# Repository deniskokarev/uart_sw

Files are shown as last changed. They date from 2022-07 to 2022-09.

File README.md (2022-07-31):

# UART Switch

This is a helper debugging device to switch the output of a proprietary box. The box connects via 2x4 Header.
There are 3 operation modes when the corresponding pins are connected:
- 0 Off: neither pins connected
- 1 SOC: (2 <-> 3) (5 <-> 6)
- 2 DBG: (2 <-> 1) (5 <-> 4) 

The device is based on STM32 microcontroller. DipTrace was used for hardware schematics and layout.
CubeMX used for USB CDC application template generaion. CLion for the rest of firmware development.

---------------------
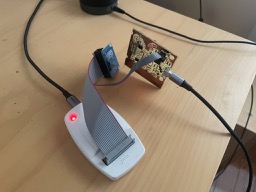
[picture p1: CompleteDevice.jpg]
Complete Device

---------------------

The modes may be switched either with a button or via serial terminal

- Directly from command line
```
echo -n "2" >/dev/cu.usbmodem1D11
```
- By Using `screen`
```
screen /dev/cu.usbmodem1D11
```
Screen Serial Terminal

The device is shows up in the USB list

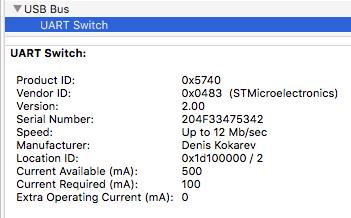
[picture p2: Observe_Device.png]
Observe in the USB device list


## [Hardware](./hardware)

## [Firmware](./firmware)

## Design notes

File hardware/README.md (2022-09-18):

# Schematic and Board Layout

The schematic and board layout was developed using DipTrace.

Schematics PDF Schematic PDF

## TODO

Fix some hardware bugs:
1) Smaller pad for inductor L1

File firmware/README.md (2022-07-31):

# Firmware

The template created with Cube MX. The code is developed using CLion.

You can tweak firmware.ioc in Cube MX and regenerate the code. Then you can continue development in CLion.

Current pins assignment:
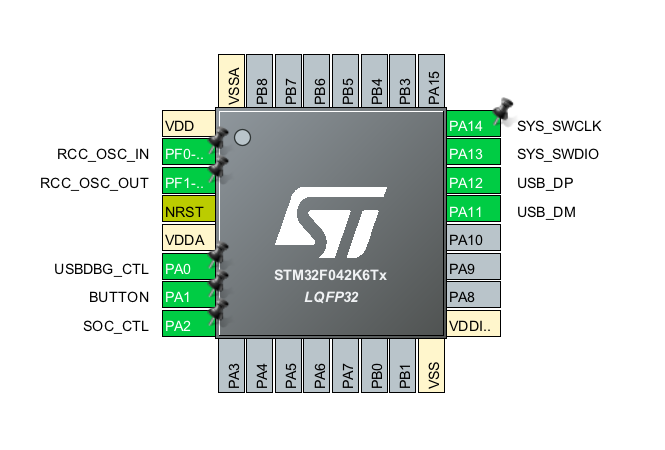
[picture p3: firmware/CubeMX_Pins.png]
CubeMX pins CubeMX Pins


# Build
Download and install ARM toolchain: https://developer.arm.com

## option 1 - CLion

- Open CLion with firmware project
```
export PATH=$PATH:/Applications/ARM/bin
open /Applications/CLion.app/ --args .
```
- Click Build

## option 2 - command line
```
export PATH=$PATH:/Applications/ARM/bin
mkdir -p cmake-build-release
cd cmake-build-release
cmake -DCMAKE_BUILD_TYPE=Release ..
cmake --build . -- -j
```

# Flash
- Using CLion
Just press `Run` - it'll use `openocd` under the hood.
- Using OpenOCD
```
brew install openocd
openocd -f ./stm32f0_via_stlink.cfg -c "program \"./cmake-build-release/firmware.elf\"" -c reset -c shutdown
```
- Using st-utils
```
brew install stlink
st-flash write cmake-build-release/firmware.bin 0x8000000
```

# Code
Functionality is included in Core/Src|Inc:
## modes.c
Custom functionality to manage modes and perform I/O. It is plugged into Cube MX template with the following 2 files:
## main.c
`HAL_GPIO_EXTI_Callback()` - button interrupt handler
`main()` - input_ch polling loop
## usbd_cdc_if.c
`CDC_Receive_FS()` - populate input_ch

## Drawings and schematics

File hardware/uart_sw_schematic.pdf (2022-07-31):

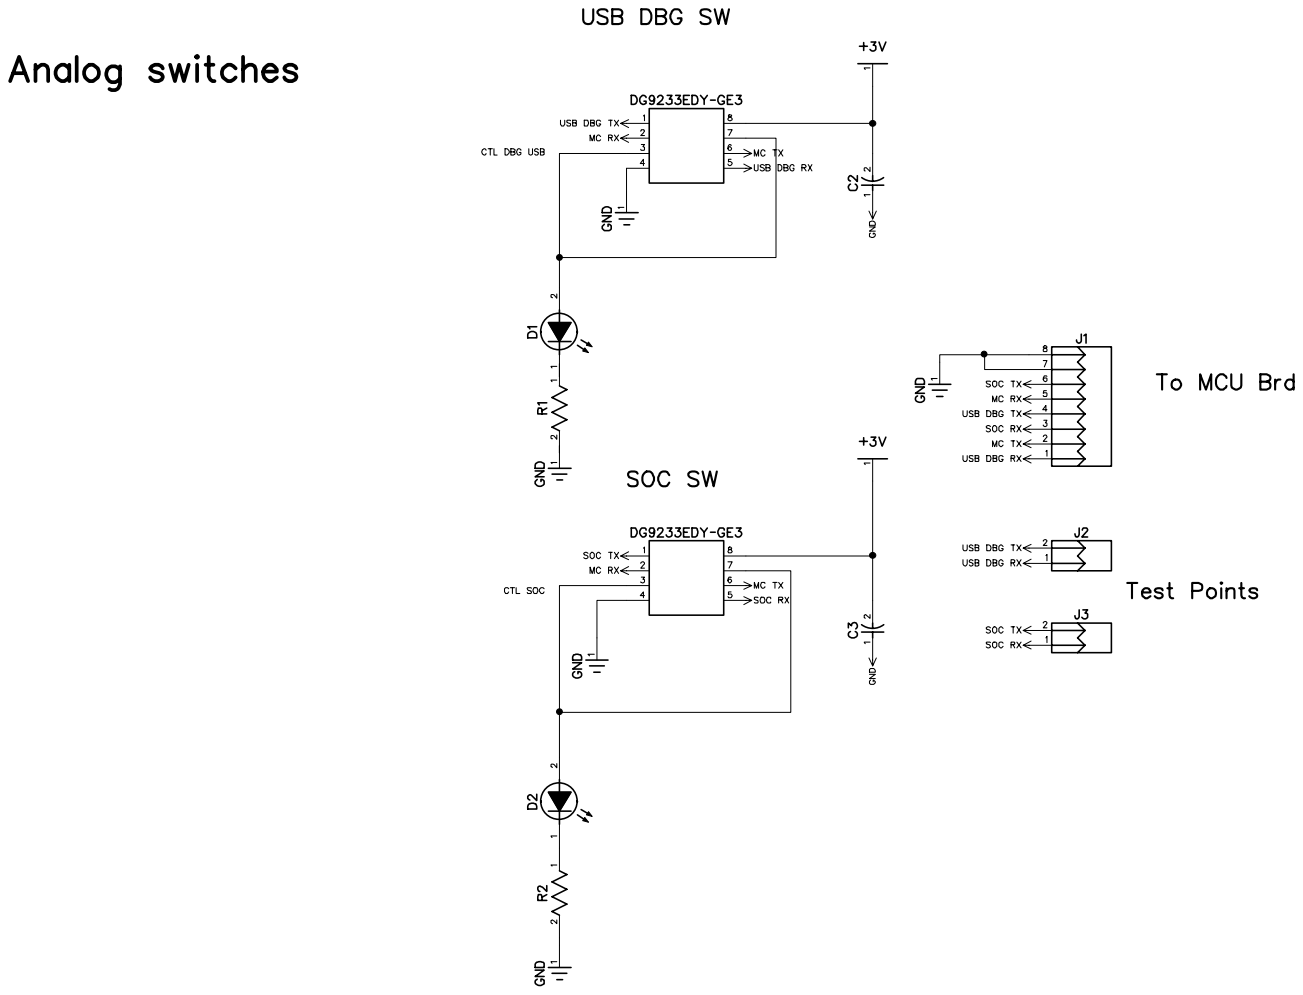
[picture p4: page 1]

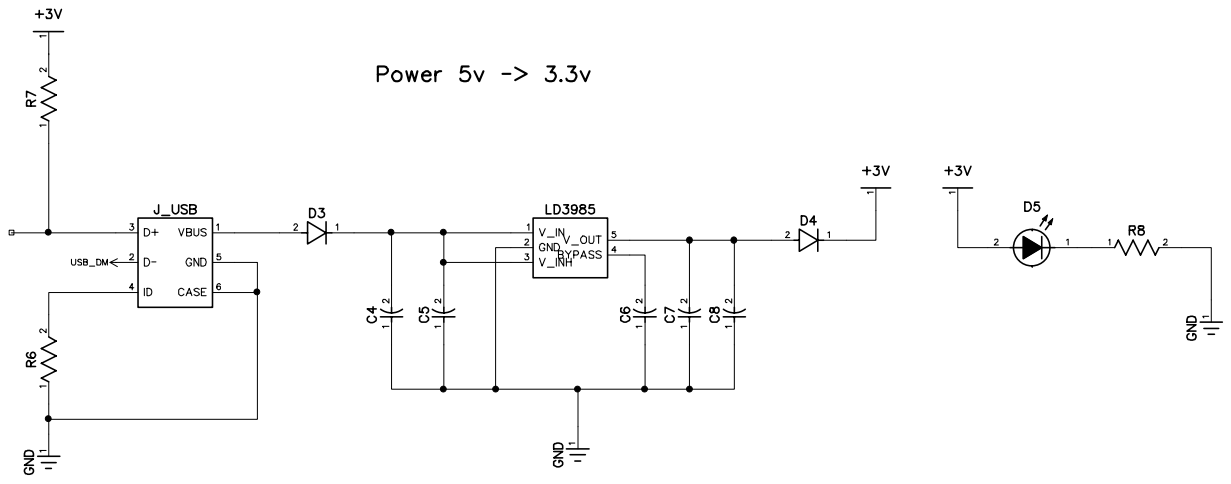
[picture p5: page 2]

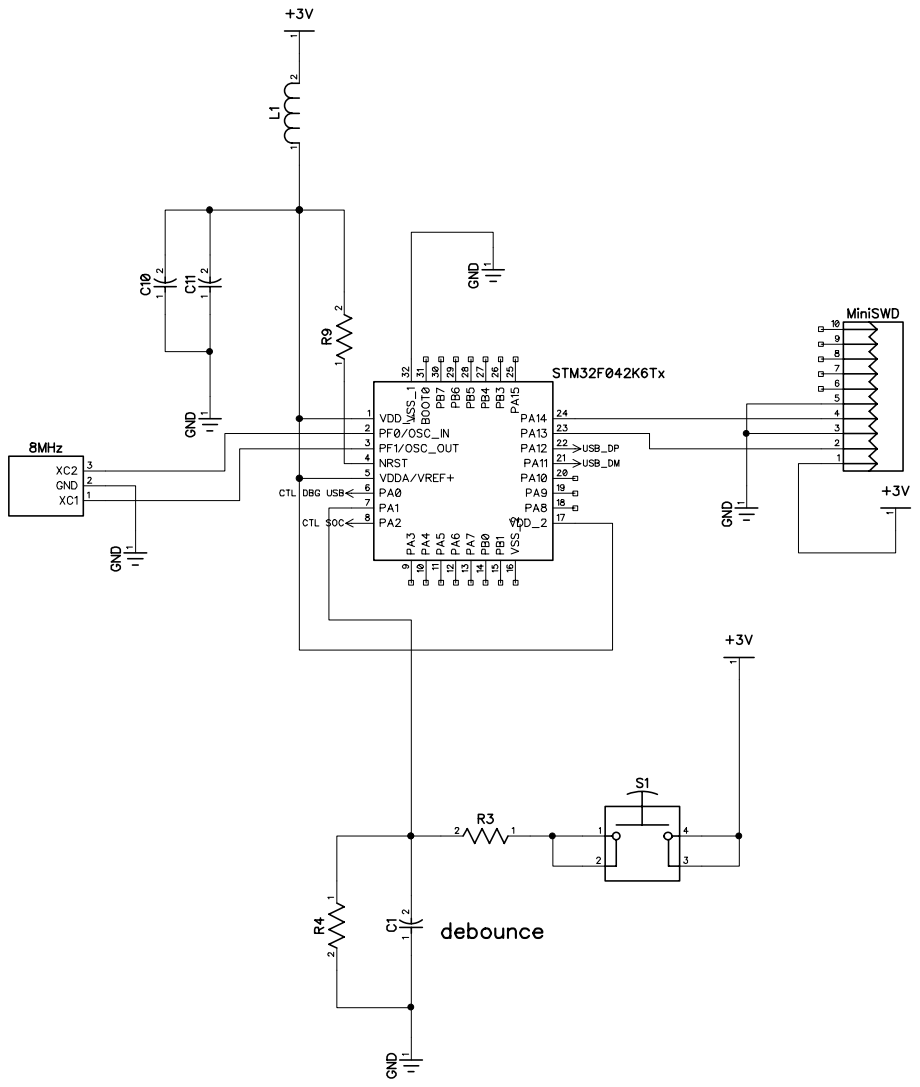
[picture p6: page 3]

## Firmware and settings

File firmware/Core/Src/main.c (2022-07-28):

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
/* Includes ------------------------------------------------------------------*/
#include "main.h"
#include "usb_device.h"

/* USER CODE BEGIN Includes */
#include "usbd_cdc_if.h"
#include "modes.h"

/* USER CODE END Includes */


void SystemClock_Config(void);
static void MX_GPIO_Init(void);
/**
  * @brief  The application entry point.
  * @retval int
  */
int main(void)
{
  /* MCU Configuration--------------------------------------------------------*/

  /* Reset of all peripherals, Initializes the Flash interface and the Systick. */
  HAL_Init();

  /* Configure the system clock */
  SystemClock_Config();

  /* Initialize all configured peripherals */
  MX_GPIO_Init();
  MX_USB_DEVICE_Init();
  /* Infinite loop */
  /* USER CODE BEGIN WHILE */
  while (1)
  {
      // keep polling input_ch populated by usb reader
      if (input_ch != 0) {
          switch (input_ch) {
              case '0':
              case '1':
              case '2':
                  set_mode(input_ch - '0');
                  break;
              default:
                  print_help();
          }
          input_ch = 0;
      }
      HAL_Delay(100);
    /* USER CODE END WHILE */

    /* USER CODE BEGIN 3 */
  }
  /* USER CODE END 3 */
}

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
/* USER CODE BEGIN 4 */
void HAL_GPIO_EXTI_Callback(uint16_t GPIO_Pin) {
    if (GPIO_Pin == BUTTON_Pin) {
        next_mode();
    }
}
/* USER CODE END 4 */
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


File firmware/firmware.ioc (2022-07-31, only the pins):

Mcu.UserName=STM32F042K6Tx
PA0.GPIO_Label=USBDBG_CTL
PA0.Signal=GPIO_Output
PA1.GPIO_Label=BUTTON
PA1.Signal=GPXTI1
PA11.Signal=USB_DM
PA12.Signal=USB_DP
PA13.Signal=SYS_SWDIO
PA14.Signal=SYS_SWCLK
PA2.GPIO_Label=SOC_CTL
PA2.Signal=GPIO_Output
PF0-OSC_IN.Signal=RCC_OSC_IN
PF1-OSC_OUT.Signal=RCC_OSC_OUT

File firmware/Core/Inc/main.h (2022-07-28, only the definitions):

#define USBDBG_CTL_Pin GPIO_PIN_0
#define USBDBG_CTL_GPIO_Port GPIOA
#define BUTTON_Pin GPIO_PIN_1
#define BUTTON_GPIO_Port GPIOA
#define BUTTON_EXTI_IRQn EXTI0_1_IRQn
#define SOC_CTL_Pin GPIO_PIN_2
#define SOC_CTL_GPIO_Port GPIOA

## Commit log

2022-07-17 Adding schematics and board layout
2022-07-17 Adding CLion CubeMX-based project
    [st_nucleo_f4.cfg]
2022-07-25 changed viewing the value instead of comp name for capacitors and resistors
2022-07-25 adding top layer gerber files for DIU
    [uart_sw2_Top.gbr, uart_sw_Top.gbr]
2022-07-27 Switching to STM32F0 standalone chip with USB support
    [st_nucleo_f4.cfg, stm32f0_via_stlink.cfg]
2022-07-28 trying to add button handler
2022-07-29 implementing button handler
2022-07-30 fixing operation with and without connected USB
    [modes.c]
2022-07-31 remaning complete device picture
2022-07-31 renaming schematics and borad layout files
    [uart_sw2_Top.gbr, uart_sw_Top.gbr]
2022-07-31 adding schematics PDF
2022-09-18 fixed hardware bugs: - GND to MC VSS pin 16 - MC NRESET connect to SWD header pin 10 - Diode D4 must protect MC from Analog Switch chips, which feedback voltage from their input to VCC There is over 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

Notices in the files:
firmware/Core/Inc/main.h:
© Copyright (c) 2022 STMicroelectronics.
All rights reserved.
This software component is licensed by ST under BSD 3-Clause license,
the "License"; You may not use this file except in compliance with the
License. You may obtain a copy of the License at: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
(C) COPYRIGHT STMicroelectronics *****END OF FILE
